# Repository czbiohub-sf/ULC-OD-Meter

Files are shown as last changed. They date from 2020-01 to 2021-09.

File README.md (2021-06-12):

# Low-Cost Portable Optical Density Meter

This repository contains all the information necessary to build CZ
Biohub's portable, low cost Optical Density (OD) Meter.

Measuring OD is a very common technique in biological laboratories to determine
the concentration of a substance in solution or of bacteria (or other particles)
in suspension. Here we present the detailed build instructions of a very simple
OD meter that costs only US$60, and can measure OD values from ~0.05 to 2.0.

## Getting Started

The full construction, setup and operating instructions are in the
complete guide file
(file "Low-Cost_Optical_Density_Meter.pdf") and at
https://www.biorxiv.org/content/10.1101/2021.05.14.444207v1

The STL files needed to 3D print the parts needed for the build are in the
"3D Printed Parts" folder.

## Super-Quick Operating Instructions

*Important:* Please let the OD meter warm up for about 20 minutes before
starting any measurements.

The OD Meter has four different states, as seen below:

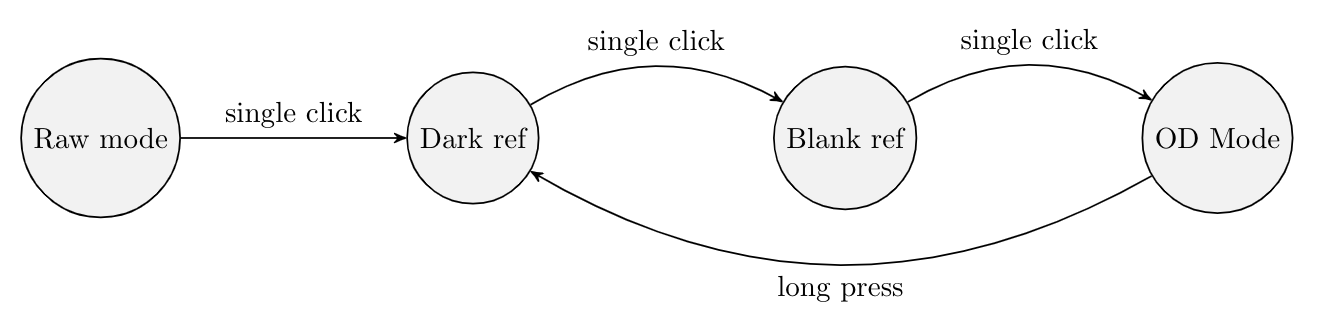
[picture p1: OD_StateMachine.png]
OD State Machine


**Raw Mode**

The system always starts up in raw mode, in which raw intensities are
displayed. This mode can be used to gauge if the Arduino has warmed up. The raw
intensities should stabilize as it warms up. Press the button once to move to
dark ref mode.

**Dark Ref Mode**

In dark ref mode, raw intensities are displayed with the label 'Dark intensity'.
In this mode, place the dark cuvette in the cuvette holder, and press the button
once to record the dark value.

**Blank Ref Mode**

In blank ref mode, raw intensities are displayed with the label 'Media
intensity'. In this mode, place the blank reference (which can be media for
bacteria, or clean water for water-based samples) in the cuvette holder, and
press the button once to record the blank value. Collecting these dark and blank
references is necessary for entering OD mode.

**OD Mode**

In OD mode, both the measured OD and the raw value are displayed on screen. If
blank and dark reference values need to be re-recorded, press down on the button
until the prompt for inserting the dark reference is displayed on the screen.

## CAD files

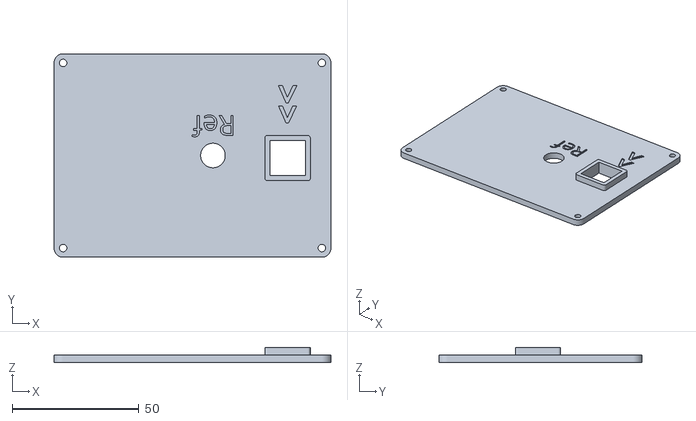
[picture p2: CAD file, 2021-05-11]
3D Printed Parts/3-0370 OD meter lid.stl
109.2 x 80.2 x 6.00

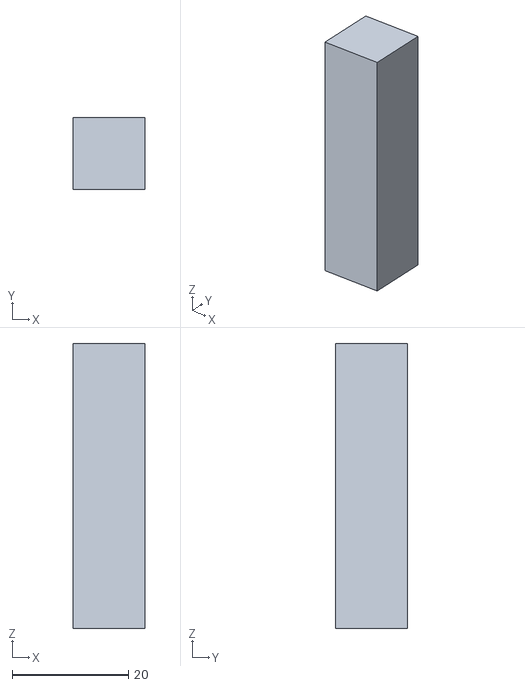
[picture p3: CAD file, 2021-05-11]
3D Printed Parts/3-0492 OD meter light-blocking insert.stl
12.3 x 12.3 x 49.0

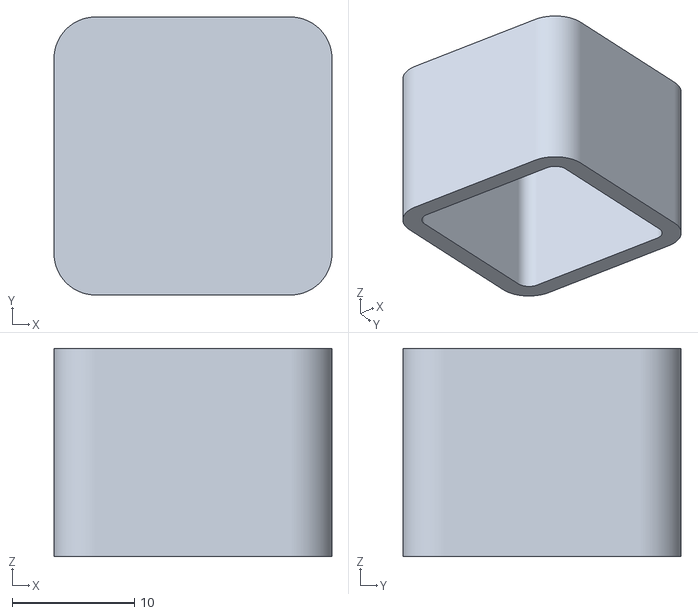
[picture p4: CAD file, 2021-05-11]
3D Printed Parts/3-0371 OD meter cuvette cap.stl
22.7 x 22.7 x 17.0

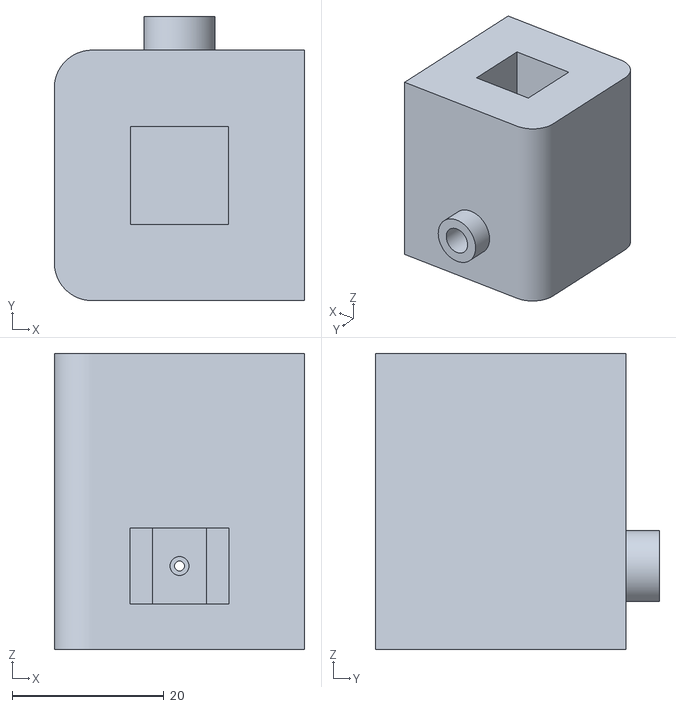
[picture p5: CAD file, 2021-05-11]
3D Printed Parts/3-0372 OD meter cuvette holder.stl
33.0 x 37.5 x 39.0

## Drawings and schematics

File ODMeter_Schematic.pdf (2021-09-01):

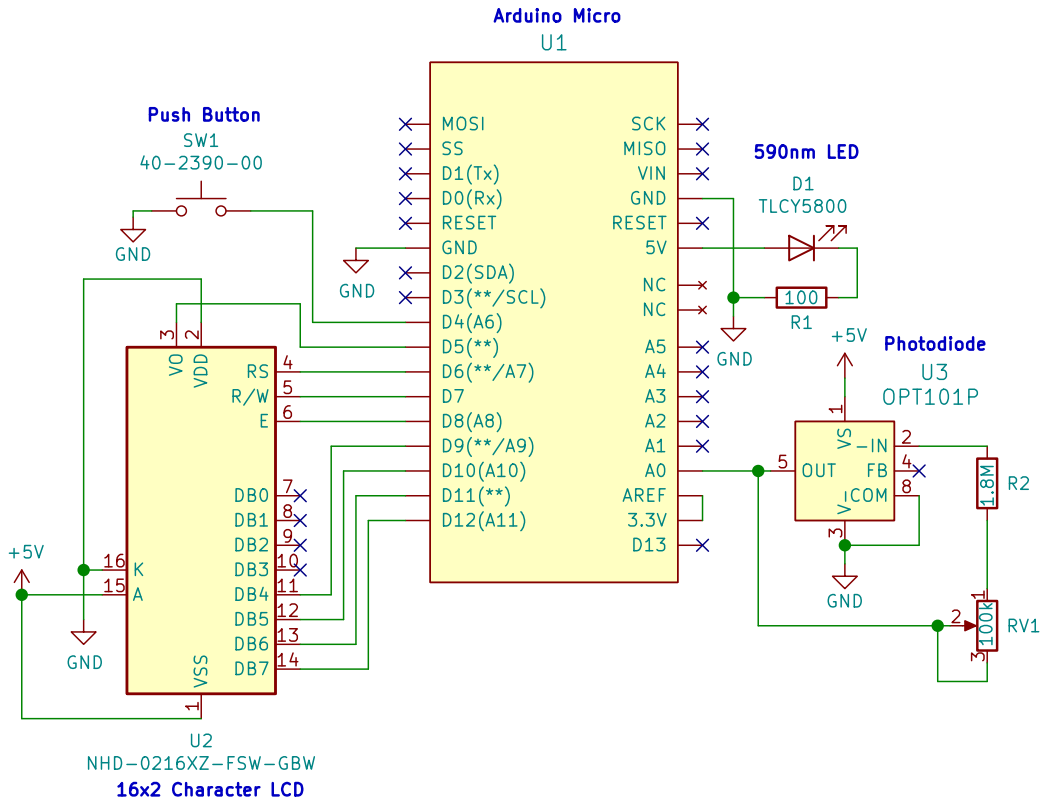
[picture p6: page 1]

Id: 1/1 Title: Ultra Low Cost OD Meter File: ODMeter.sch Sheet: / Chan Zuckerberg Biohub VSS

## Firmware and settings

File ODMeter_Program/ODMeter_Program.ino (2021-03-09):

#include <LiquidCrystal.h>
#include <math.h>

//Arduino pins
const int output_photodiode = A0;
const int button_input = 3;
const int lcd_contrast = 5;
const int rs = 6, rw = 7, en = 8, d4 = 9, d5 = 10, d6 = 11, d7 = 12;

//Program variables
int new_read = 0;
int sum_of_reads = 0;
int sample_counts = 0;
int thresh_counts = 20;
int value = 0;
volatile unsigned long t_now = 0;
volatile unsigned long t_last = 0;


volatile int dark_counts = 0;
volatile int ref_counts = 0;
volatile bool ref_captured = false;
int t_debounce_ms = 200;
volatile bool reset_to_raw = false;
volatile int state = 0;
volatile int stored_next_state = 0;

int b;

//Initialize LCD and function prototype
LiquidCrystal lcd(rs, rw, en, d4, d5, d6, d7);

void setup() {
  //Pin setup
  Serial.begin(9600);
  Serial.println("Starting");
  analogReference(EXTERNAL);
  analogRead(output_photodiode);
  analogWrite(lcd_contrast, 40);
  pinMode(button_input, INPUT_PULLUP);

  //Set welcome screen
  lcd.begin(16, 2);
  lcd.print("   CZ Biohub");
  lcd.setCursor(0,1);
  lcd.print("    OD Meter");
  delay(2000);

  //Show raw intensity at startup
  state = 0;
  lcd.clear();
  lcd.print("Raw intensity:");
  attachInterrupt(digitalPinToInterrupt(button_input), askDarkISR, LOW);

}

void loop() {
  //Add reads until thresh_counts counts have been summed
  new_read = analogRead(output_photodiode);
  sum_of_reads = sum_of_reads + new_read;
  sample_counts = sample_counts + 1;
  Serial.println(state);
  switch (state) {
    case 0: // raw reading
       // average the readings once the sample count threshold is met
      if (sample_counts >= thresh_counts) {
        value = (sum_of_reads / thresh_counts);
        Serial.println("In state 0 about to print number");
        printNumber(value);
        sample_counts = 0;
        sum_of_reads = 0;
      }
      break;

    case 1: // asking for dark ref
      Serial.println("asking for dark ref");
      lcd.clear();
      lcd.print("Insert dark ref");
      lcd.setCursor(0, 1);
      lcd.print("press REF button");
      delay(2000);
    
      lcd.clear();
      lcd.print("press REF button");
      lcd.setCursor(0,1);
      lcd.print("when ready.");
      delay(1500);
      
      lcd.clear();
      lcd.print("Dark intensity:");

      if (digitalRead(button_input) == LOW) {
        // Check if the button is being pressed at the moment --
        // if it is, then attach a temporary interrupt that waits for the button
        // to change state to high. When it does, it attaches the correct ISR,
        // based on the stored_next_state variable.
        attachInterrupt(digitalPinToInterrupt(button_input), tempISR, HIGH);
        stored_next_state = 1;
      } else {
        attachInterrupt(digitalPinToInterrupt(button_input), captureDarkISR, LOW);
      }
        
      state = 0;
      break;

    case 2: //asking for media ref
      Serial.println("asking for media ref");
      lcd.clear();
      lcd.print("Insert media ref");
      lcd.setCursor(0, 1);
      lcd.print("press REF button");
      delay(2000);
    
      lcd.clear();
      lcd.print("press REF button");
      lcd.setCursor(0,1);
      lcd.print("when ready.");
      delay(1500);
    
      lcd.clear();
      lcd.print("Media intensity:");
      
      if (digitalRead(button_input) == LOW) {
         // Check if the button is being pressed at the moment --
        // if it is, then attach a temporary interrupt that waits for the button
        // to change state to high. When it does, it attaches the correct ISR,
        // based on the stored_next_state variable.
        attachInterrupt(digitalPinToInterrupt(button_input), tempISR, HIGH);
        stored_next_state = 2;
      } else {
        attachInterrupt(digitalPinToInterrupt(button_input), captureMediaISR, LOW);
      }
      state = 0;
      break;
          
    
    case 3: // OD reading
      b = checkButton();
      if (b == 2) {
        attachInterrupt(digitalPinToInterrupt(button_input), askDarkISR, LOW);
        state=1;
        
      }
      if (sample_counts == thresh_counts) {
        value = (sum_of_reads / thresh_counts);
        float od = -1.0 * log10(float(value-dark_counts) / float(ref_counts-dark_counts));
        // Print out OD
        lcd.setCursor(1,1);
        lcd.print(od,3);
  
        // Print out raw value
        lcd.setCursor(12,1);
        lcd.print(value);
        sample_counts = 0;
        sum_of_reads = 0;
      }
      
      break;
     
  }
  delay(10);
}

//Print number to LCD
void printNumber(float number){
  lcd.setCursor(6, 1);
  lcd.print("    ");
  lcd.setCursor(6, 1);
  lcd.print(number,3);
}

//Button callbacks
void tempISR(void) {
  t_now = millis();
  if ((t_now - t_last) > t_debounce_ms) {
    detachInterrupt(digitalPinToInterrupt(button_input));
    if (digitalRead(button_input) == LOW) {
      attachInterrupt(digitalPinToInterrupt(button_input), tempISR, HIGH);
    } else {
      if (stored_next_state == 1) {
        attachInterrupt(digitalPinToInterrupt(button_input), captureDarkISR, LOW);
      } else {
        // it equals 2
        attachInterrupt(digitalPinToInterrupt(button_input), captureMediaISR, LOW);
      }     
    }
 
  }
}


void askDarkISR(void){
  t_now = millis();
  if ((t_now - t_last) > t_debounce_ms){
    detachInterrupt(digitalPinToInterrupt(button_input));
    state = 1;
  }
  t_last = t_now;
}

void captureDarkISR(void){
  t_now = millis();
  if ((t_now - t_last) > t_debounce_ms){
    detachInterrupt(digitalPinToInterrupt(button_input));
    dark_counts = value;
    state = 2;
  }
  t_last = t_now;
}

void askMediaISR(void){
  t_now = millis();
  if ((t_now - t_last) > t_debounce_ms){
    detachInterrupt(digitalPinToInterrupt(button_input));
    state = 2;
  }
  t_last = t_now;
}

void captureMediaISR(void){
  t_now = millis();
  if ((t_now - t_last) > t_debounce_ms){
    detachInterrupt(digitalPinToInterrupt(button_input));
    ref_counts = value;
    lcd.clear();
    lcd.setCursor(1,0);
    lcd.print("OD:");
    lcd.setCursor(11,0);
    lcd.print("Raw:");
    state = 3;
  }
  t_last = t_now;
}
//=================================================
//  MULTI-CLICK:  One Button, Multiple Events

// Button timing variables
int debounce = 200;          // ms debounce period to prevent flickering when pressing or releasing the button
int DCgap = 280;            // max ms between clicks for a double click event
int holdTime = 1000;        // ms hold period: how long to wait for press+hold event

// Button variables
boolean buttonVal = HIGH;   // value read from button
boolean buttonLast = HIGH;  // buffered value of the button's previous state
boolean DCwaiting = false;  // whether we're waiting for a double click (down)
boolean DConUp = false;     // whether to register a double click on next release, or whether to wait and click
boolean singleOK = true;    // whether it's OK to do a single click
long downTime = -1;         // time the button was pressed down
long upTime = -1;           // time the button was released
boolean ignoreUp = false;   // whether to ignore the button release because the click+hold was triggered
boolean waitForUp = false;        // when held, whether to wait for the up event
boolean holdEventPast = false;    // whether or not the hold event happened already

int checkButton() {   
   int event = 0;
   buttonVal = digitalRead(button_input);
   // Button pressed down
   if (buttonVal == LOW && buttonLast == HIGH && (millis() - upTime) > debounce)
   {
       downTime = millis();
       ignoreUp = false;
       waitForUp = false;
       singleOK = true;
       holdEventPast = false;
       if ((millis()-upTime) < DCgap && DConUp == false && DCwaiting == true)  DConUp = true;
       else  DConUp = false;
       DCwaiting = false;
   }
   // Button released
   else if (buttonVal == HIGH && buttonLast == LOW && (millis() - downTime) > debounce)
   {       
       if (not ignoreUp)
       {
           upTime = millis();
           if (DConUp == false) DCwaiting = true;
       }
   }
   // Test for normal click event: DCgap expired
   if ( buttonVal == HIGH && (millis()-upTime) >= DCgap && DCwaiting == true && DConUp == false && singleOK == true && event != 2)
   {
       event = 1;
       DCwaiting = false;
   }
   // Test for hold
   if (buttonVal == LOW && (millis() - downTime) >= holdTime) {
       // Trigger "normal" hold
       if (not holdEventPast)
       {
           event = 2;
           waitForUp = true;
           ignoreUp = true;
           DConUp = false;
           DCwaiting = false;
           holdEventPast = true;
       }
 
   }
   buttonLast = buttonVal;
   return event;
} // End of checkButton()

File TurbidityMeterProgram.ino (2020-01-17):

#include <LiquidCrystal.h>
#include <math.h>

//Arduino pins
const int output_photodiode = A0;
const int button_input = 4
const int lcd_contrast = 5;
const int rs = 6, rw = 7, en = 8, d4 = 9, d5 = 10, d6 = 11, d7 = 12;

//Program variables
int new_read = 0;
int sum_of_reads = 0;
int sample_counts = 0;
int thresh_counts = 20;
volatile int ref_counts = 0;
volatile bool ref_captured = false;

//Initialize LCD and function prototype
LiquidCrystal lcd(rs, rw, en, d4, d5, d6, d7);
void printCounts(int);
void referenceISR(void);

void setup() {
  //Pin setup
  analogReference(EXTERNAL);
  analogRead(output_photodiode);
  analogWrite(lcd_contrast, 40);
  pinMode(button_input, INPUT_PULLUP);
  attachInterrupt(digitalPinToInterrupt(button_input), referenceISR, RISING);

  //Set welcome screen
  lcd.begin(16, 2);
  lcd.print("CZ Biohub");
  lcd.setCursor(0,1);
  lcd.print("Turbidity Meter");
  delay(2000);

  lcd.clear();
  lcd.print("Insert blank and");
  lcd.setCursor(0, 1);
  lcd.print("press REF button");
  delay(2000);

  lcd.clear();
  lcd.print("press REF button");
  lcd.setCursor(0,1);
  lcd.print("when ready.");
  delay(1500);

  //Reset display
  lcd.clear();
  lcd.print("Raw intensity:");
}

void loop() {
  //Add reads until 20 counts have been summed
  new_read = analogRead(output_photodiode);
  sum_of_reads = sum_of_reads + new_read;
  sample_counts = sample_counts + 1;

  //Print to display when threhs_counts reached and reset vars
  if (sample_counts == thresh_counts && ref_captured == false)
  {
    printNumber(sum_of_reads / thresh_counts);
    sample_counts = 0;
    sum_of_reads = 0;
  }
  else if (sample_counts == thresh_counts && ref_captured == true)
  {
    printNumber(log10( ref_captured / (sum_of_reads/thresh_counts) ));
    sample_counts = 0;
    sum_of_reads = 0;
  }

  delay(15);
}

//Print number to LCD
void printNumber(int number){
  lcd.setCursor(6, 1);
  lcd.print("    ");
  lcd.setCursor(6, 1);
  lcd.print(number);
}

//Button callback
void referenceISR(void){
  ref_counts = analogRead(output_photodiode);
  ref_captured = true;
}

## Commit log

2020-01-16 Add initial schematic files
    [Schematic.kicad_pcb, Schematic.sch]
2020-01-16 Update schematic
2020-01-17 Add initial Arduino code
    [Schematic.sch]
2020-01-28 Change schematic and remove excess files
    [ODMeter.sch, Schematic.kicad_pcb, Schematic.sch]
2020-07-13 Add double press to reset to raw counts
    [ODMeter_Program.ino]
2021-01-26 Hold button implementation
2021-01-26 uploading experimental version of OD meter to show raw and od simultaneously
    case 3 is showing the raw reading on top and the OD on the bottom of the screen
2021-03-04 Edited sample counts threshold and tempISR
2021-03-04 Removed print statements
2021-04-02 updated schematic
2021-04-02 updated kicad
    [ODMeter.sch]
2021-04-21 Connected wiper to 3rd pin
    [ODMeter.sch]
2021-05-11 Added license and files for 3D printing.
    [3-0370 OD meter lid.stl, 3-0371 OD meter cuvette cap.stl, 3-0372 OD meter cuvette holder.stl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]
2021-09-01 Fixed AREF on schematic
    [ODMeter.sch]
